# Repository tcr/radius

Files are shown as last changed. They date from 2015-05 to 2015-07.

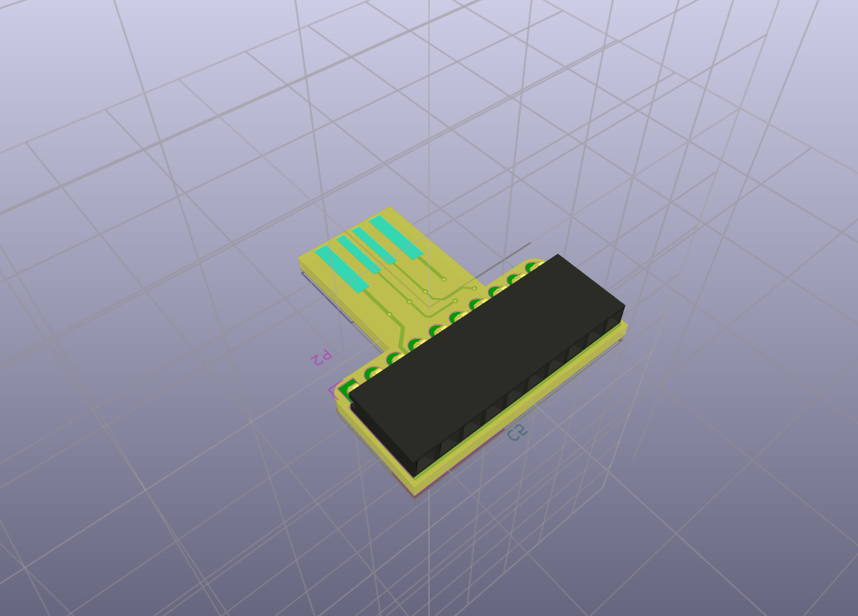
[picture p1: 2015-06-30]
board/renders/radiusm.png

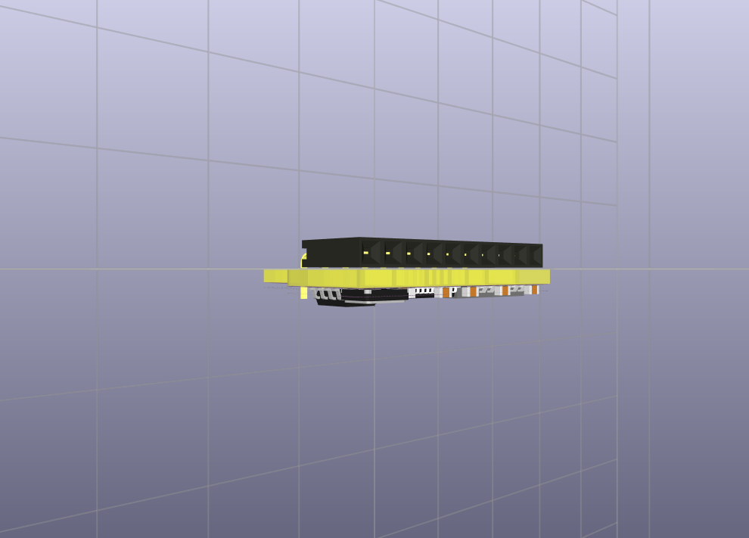
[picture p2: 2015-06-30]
board/renders/radius.png

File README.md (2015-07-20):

# radius



## testing

```
make
make flash
make test
```

If OS X reports contention for your device:

```
sudo kextunload -b com.apple.driver.AppleUSBCardReader
sudo kextunload -b com.apple.iokit.IOUSBMassStorageClass
```

## parts

Designator(s) | Quantity | Description | Part Number
--- | --- | --- | ---
IC1 | 1 | STM8S 8-bit micro (TSSOP-20) | [STM8S003F3P6](http://www.digikey.com/product-detail/en/STM8S003F3P6/497-11946-5-ND/2765682)
P2 | 1 | 10-pin right-angled header, .1" Pitch | [PPTC101LGBN-RC](http://www.digikey.com/product-search/en?KeyWords=S5446-ND&WT.z_header=search_go)
U1 | 1 | Full speed USB <-> 9-pin Serial (SOP-16) | CH340G
U2 | 1 | 3.3V Regulator (SO-8) | [LD1117D33CTR](http://www.digikey.com/scripts/DkSearch/dksus.dll?Detail&itemSeq=175125035&uq=635712533888642171)
Y1 | 1 | 12Mhz Crystal | [NX3225SA](http://www.digikey.com/product-detail/en/NX3225SA-12.000MHZ-STD-CSR-1/644-1047-1-ND/1128919)
C1 | 1 | 0.1 uF (0603) | ...
C2 | 1 | 10 uF (0603) | ...
C3 | 1 | 1 μF polarized (0603) | ...
C4, C5 | 2 | 20 pF (0603) | ...

* [STM8 Reference design](http://www.st.com/web/en/resource/technical/document/application_note/CD00194637.pdf#page=19)

## pin mapping

* GND
* 3.3V
* SCL - PB4
* SDA - PB5
* SCK - PC5
* MISO - PC7
* MOSI - PC6
* TXD - PD2
* RXD - PD0
* G3 - PD1

USB:

* TXD - PD6
* RXD - PD5

## docs

Reference manual: http://www.st.com/web/en/resource/technical/document/reference_manual/CD00190271.pdf

 * SPI: http://www.st.com/web/en/resource/technical/document/reference_manual/CD00190271.pdf#page=259
 * I2C: http://www.st.com/web/en/resource/technical/document/reference_manual/CD00190271.pdf#page=285
 * GPIO: http://www.st.com/web/en/resource/technical/document/reference_manual/CD00190271.pdf#page=106
 * UART: http://www.st.com/web/en/resource/technical/document/reference_manual/CD00190271.pdf#page=318

CPU reference: http://www.st.com/web/en/resource/technical/document/programming_manual/CD00161709.pdf

Product Datasheet: http://www.st.com/web/en/resource/technical/document/datasheet/DM00024550.pdf

 * Memory map: http://www.st.com/web/en/resource/technical/document/datasheet/DM00024550.pdf#page=32
 * Pin map: http://www.st.com/web/en/resource/technical/document/datasheet/DM00024550.pdf#page=22

 Errata: http://postar.sino-star.com/public/uploads/20120214161049_871.pdf

## CH340G

Datasheet: http://www.seeedstudio.com/wiki/images/7/7c/CH340DS1_EN.PDF

## tools

https://github.com/vdudouyt/stm8flash

```
brew install sdcc
```

http://www.colecovision.eu/stm8/128-EVAL%20Dhrystone.shtml

## how it works

interrupts are priority-based outputs in 64 byte packets. priority output is real time input of "uniterruptable streams", specifically i2c read (max 920Khz) and uart input (max 18400bps) simultaneously

also note that i2c can stretch clock lines so really it's only uart interrupts

there are many buffers, but this one is mine(d) for its outputting content. all packets block on new input until it's swapped for the outputting. so buffers must clean faster than they collectively are filled for uninterruptable streams (and acks).

output from radius is asap and dumped into its buffers. simple packet id +  NACK/ACK acknowledgement byte on the usb line.

ID0 + NACK/ACK
ID1 + LEN + <=64 byte packet

input? it is 64 byte packets. wait for an nack, then resend, or continue

LEN + <=64 byte packet

input is synced at start by waiting for an 'R' on both sides

packets are USB-style repeated until a 0 length packet or < 64 length packet is received

## license

MIT/ASL2

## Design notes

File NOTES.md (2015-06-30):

--------  --------
WRIPKT
  -------- --------
  RECV RX

RX faster than TX

async events have no ack, simply are expected to be sent out when buffered and have their buffer cleared before more data comes in

thus tx needs to be faster than rx for async
if there are two async streams, faster than both buffers filling simultaneously
double-buffered so it's always cleared first

swapped buffers for data reception for each channel
so, 4 out + 4 in + 2 active buffers

I2C TRANSFER OUT

TX double buffer
RX double buffer

enum ack_t {
	NACK = 0x00,
	ACK,
}

enum out_t {
	OUT_CONTROL = 0x10,
	OUT_I2C,
	OUT_UART,
	OUT_SPI,
};

enum in_t {
	IN_UART = 0x20,
	IN_SPI,
	IN_I2C,
	IN_GPIO (interupt or read)
};

SETUP [CONTROL TRANSFER]
- begin i2c transfer; tx and rx
- begin spi transfer; tx and rx
- begin uart transfer; tx
- set gpio output and/or read
- 

data packets
-> [byte] [16 bytes]
<- [ack] or [nack]
<- or impulse

OUT -> I2C MASTER TX
OUT -> UART TX
OUT -> SPI MASTER TX

IN -> UART RX (hi-pri)
IN -> I2C MASTER RX
IN -> SPI MASTER RX
IN -> GPIO INTERRUPT OR READ

1. uart fills buffers
2. main loop handles control elements buffers
3. other loops handle other buffers
4. acks only when empty

(so data packet of i2c data preceding i2c transfer is ok)

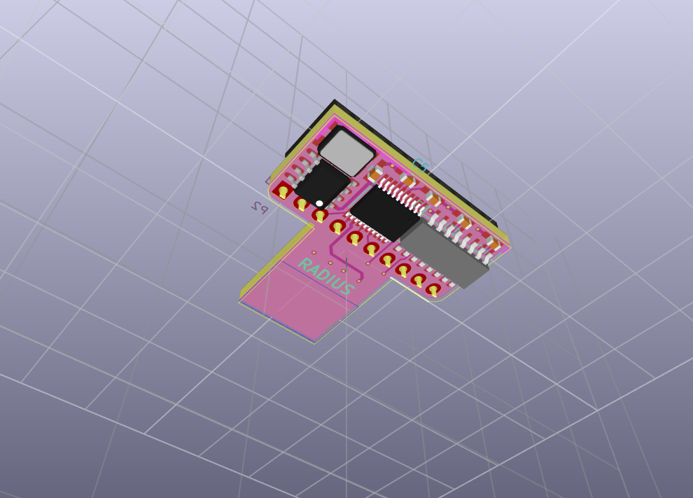
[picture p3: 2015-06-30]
board/renders/radiusn.png

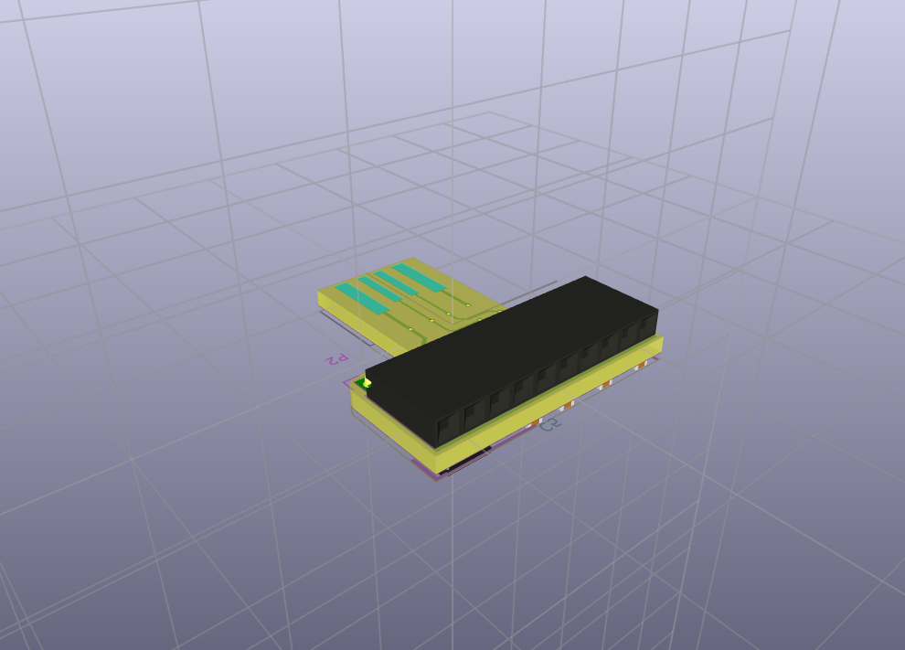
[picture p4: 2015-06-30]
board/renders/radiusj.png

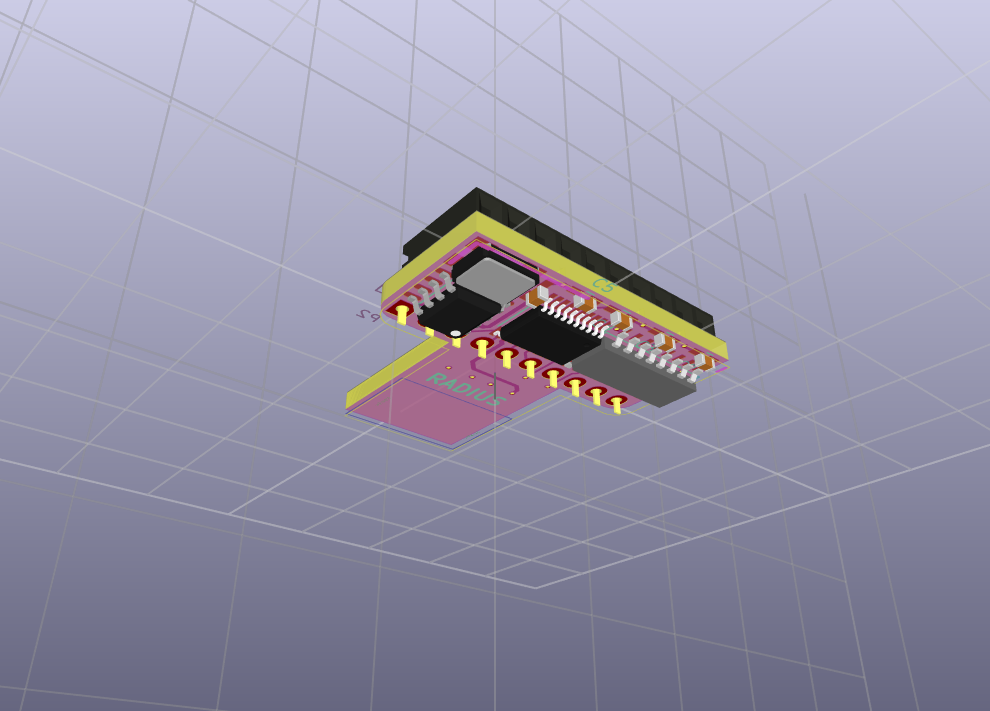
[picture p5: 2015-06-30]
board/renders/radiusk.png

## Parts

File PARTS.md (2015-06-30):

10 - 0.5 = 9.5

8

BOM=2.5

cpu=~1
#stm32f0=~0.5

attiny24=~0.42
https://octopart-clicks.com/click/track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
https://www.obdev.at/products/vusb/index.html

CH340G
http://www.aliexpress.com/wholesale?SearchText=CH340G&opensearch=true
~0.21-0.37

stm8s=~0.22-0.33
https://octopart-clicks.com/click/track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
http://www.aliexpress.com/w/wholesale-stm8s.html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
http://www.st.com/web/en/resource/technical/document/application_note/CD00194637.pdf

power
http://www.digikey.com/product-search/en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
0.15-0.23

header
http://www.digikey.com/product-detail/en/PPTC101LGBN-RC/S5446-ND/775904
0.58-.94

crystal

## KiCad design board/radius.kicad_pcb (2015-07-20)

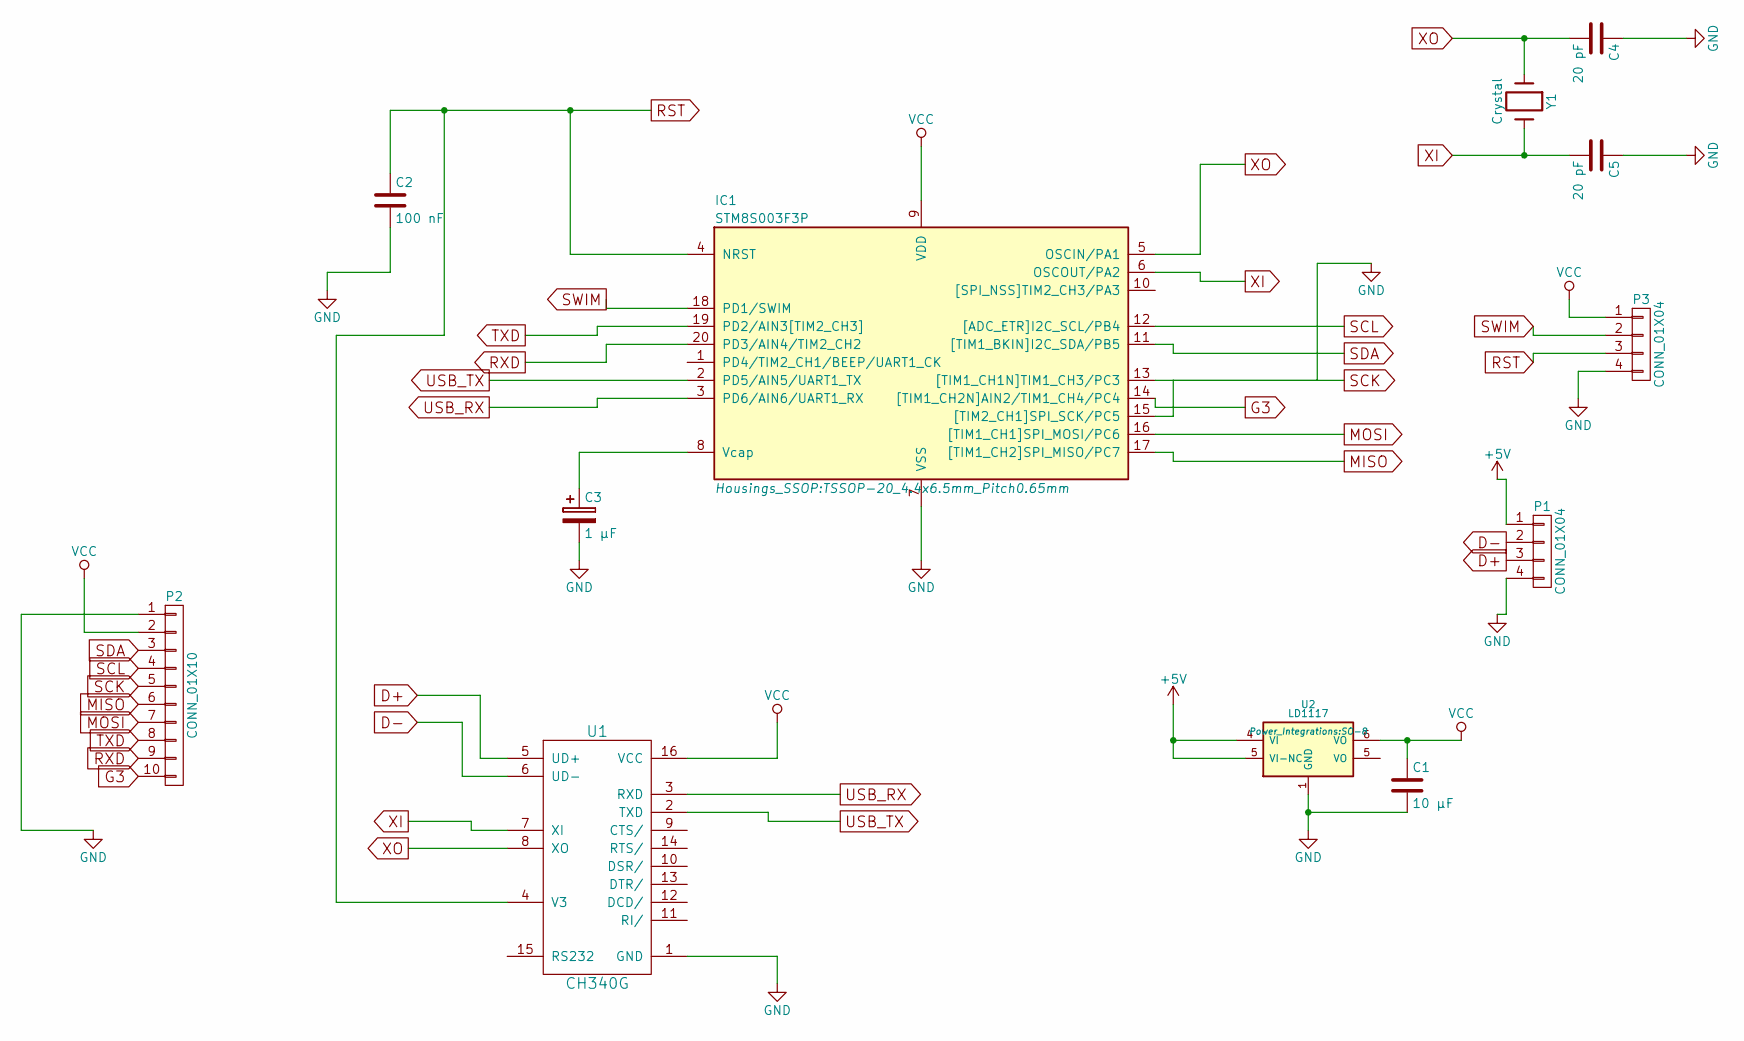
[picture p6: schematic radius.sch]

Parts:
C1: 10 µF; C_0603_HandSoldering
C2: 100 nF; C_0603_HandSoldering
C3: 1 μF; C_0603_HandSoldering
C4, C5: 20 pF; C_0603_HandSoldering
IC1: STM8S003F3P; TSSOP-20_4.4x6.5mm_Pitch0.65mm
P1: CONN_01X04; USB-A-PCB
P2: CONN_01X10; Socket_Strip_Angled_1x10
P3: CONN_01X04; RADIUS-CONN-2MM-M-1x4
U1: CH340G; SO-16-N
U2: LD1117; SO-8
Y1: Crystal; Crystal_SMD_0603_4Pads

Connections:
+5V: P1.1, U2.4 (VI), U2.5 (VI-NC)
D+: P1.3, U1.5 (UD+)
D-: P1.2, U1.6 (UD-)
G3: IC1.14 ([TIM1_CH2N]AIN2/TIM1_CH4/PC4), P2.10
GND: C1.2, C2.2, C3.2, C4.1, C5.1, IC1.7 (VSS), IC1.13 ([TIM1_CH1N]TIM1_CH3/PC3), P1.4, P2.1, P3.4, U1.1 (GND), U2.1 (GND)
MISO: IC1.17 ([TIM1_CH2]SPI_MISO/PC7), P2.6
MOSI: IC1.16 ([TIM1_CH1]SPI_MOSI/PC6), P2.7
unnamed: C3.1, IC1.8 (Vcap)
RST: C2.1, IC1.4 (NRST), P3.3, U1.4 (V3)
RXD: IC1.20 (PD3/AIN4/TIM2_CH2), P2.9
SCK: IC1.15 ([TIM2_CH1]SPI_SCK/PC5), P2.5
SCL: IC1.12 ([ADC_ETR]I2C_SCL/PB4), P2.4
SDA: IC1.11 ([TIM1_BKIN]I2C_SDA/PB5), P2.3
SWIM: IC1.18 (PD1/SWIM), P3.2
TXD: IC1.19 (PD2/AIN3[TIM2_CH3]), P2.8
USB_RX: IC1.3 (PD6/AIN6/UART1_RX), U1.3 (RXD)
USB_TX: IC1.2 (PD5/AIN5/UART1_TX), U1.2 (TXD)
VCC: C1.1, IC1.9 (VDD), P2.2, P3.1, U1.16 (VCC), U2.6 (VO)
XI: C5.2, IC1.6 (OSCOUT/PA2), U1.7 (XI), Y1.2
XO: C4.2, IC1.5 (OSCIN/PA1), U1.8 (XO), Y1.1

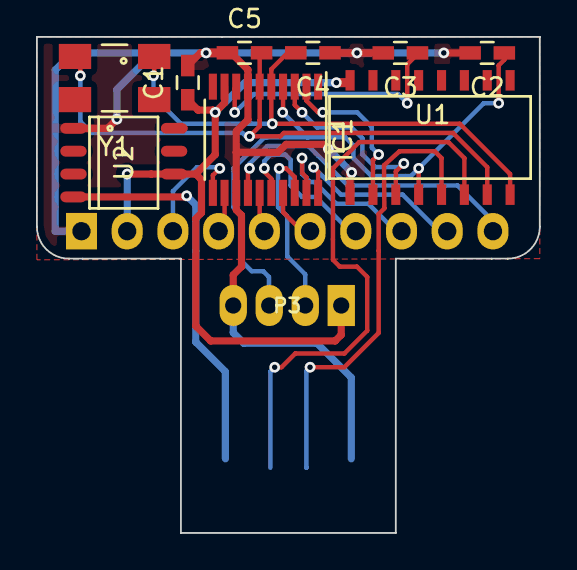
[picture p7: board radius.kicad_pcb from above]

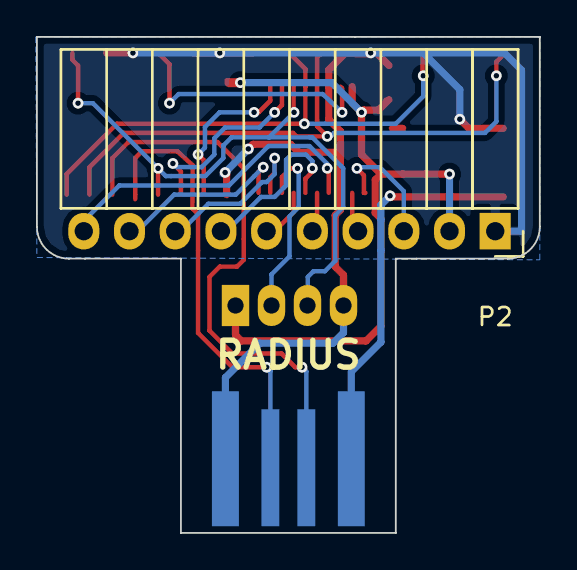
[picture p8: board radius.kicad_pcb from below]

Board: 2 copper layers, 27.9 x 27.6 mm, 12 parts (2 on the bottom side), 20 nets.

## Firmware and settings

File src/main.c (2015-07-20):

#include <stdio.h>
#include <string.h>
#include <stdint.h>

#include "stm8s.h"
#include "lib.h"
#include "coroutine.h"

char uartstr[16] = "\0\0\0\0\0\0\0\0\0\0\0\0\0\0\0";
const uint8_t uartstr_len = 12;
volatile uint8_t pos = 0;

volatile uint8_t I2C_ReadByte_Result_Addr = 0;
volatile uint8_t I2C_ReadByte_Result_Reg = 0;
volatile uint8_t I2C_ReadByte_Result_Ready = 1;
volatile uint8_t I2C_ReadByte_Result_Value[32] = { 0 };
volatile size_t I2C_ReadByte_Count = 0;
volatile size_t I2C_ReadByte_Pos = 0;

void irq_i2c (void) __interrupt(IRQ_I2C) {
    static uint8_t Temp, Byte_Read;

    scr_begin;

    gpio_write(0, 1);
    while (I2C_ReadByte_Result_Ready) {
        scr_return_void;
    }

    // while((I2C_SR3 & 0x02) != 0);

    while ((I2C_SR1 & 0x01) == 0) { //Start condition generated
        scr_return_void;
    }

    I2C_DR = (I2C_ReadByte_Result_Addr << 1);         //Device address
    // if ((I2C_SR1 & 0x80) == 0); //Data register empty (transmitters)
    while ((I2C_SR1 & 0x02) == 0) { //Address sent
        scr_return_void;
    }
    Temp = I2C_SR3;        //Status register

    I2C_DR = I2C_ReadByte_Result_Reg;         //Device register
    while ((I2C_SR1 & 0x80) == 0) { //Data register empty (transmitters)
        scr_return_void;
    }

    // Writing
    // I2C_DR = Data;         //Device data
    // while((I2C_SR1 & 0x80) == 0); //Data register empty (transmitters)
    // I2C_CR2 |= 0x02;        //I2C Stop Condition
    // This might be wrong; other code used a wait?
    // while ((I2C_SR1 & 0x40) == 0) { //Byte transfer finished
    //   scr_return_void;
    // }
    // i = 0xFFFF;
    // while(i--);
    // scr_finish_void;

    I2C_CR2 |= 0x01;        //I2C Start Condition
    while ((I2C_SR1 & 0x01) == 0) { //Start condition generated
        scr_return_void;
    }

    I2C_DR = ((I2C_ReadByte_Result_Addr << 1) | 0x01);    //Device address(read)
    scr_return_void;
    while ((I2C_SR1 & 0x02) == 0) { //Address sent
        scr_return_void;
    }
    Temp = I2C_SR3;        //Status register

    do {
        if (I2C_ReadByte_Count > 1) {
            I2C_CR2 |= 0x04;        //I2C Ack Condition
        } else {
            I2C_CR2 |= 0x02;        //I2C Stop Condition
        }
        scr_return_void;

        while ((I2C_SR1 & 0x40) == 0) { //Byte transfer finished
          scr_return_void;
        }
        // Byte_Read = 0x00;        //Clean data
        I2C_ReadByte_Result_Value[I2C_ReadByte_Pos++] = I2C_DR;
    } while ((--I2C_ReadByte_Count) > 0);

    I2C_ReadByte_Result_Ready = 1;

    scr_finish_void;
}

void i2c_read_bytes (uint8_t addr, uint8_t reg, size_t count) {
    I2C_ReadByte_Result_Addr = addr;
    I2C_ReadByte_Result_Reg = reg;
    I2C_ReadByte_Count = count;
    I2C_ReadByte_Pos = 0;
    I2C_ReadByte_Result_Ready = 0;
    gpio_write(0, 0);
    I2C_CR2 |= 0x01;        //I2C Start Condition
}

uint8_t i2c_read_byte_result () {
    return I2C_ReadByte_Result_Ready ? 0 : 1;
}

void write_chars (char* to, uint8_t val) {
    uint8_t high = val >> 4;
    uint8_t low = val & 0xf;
    to[0] = high > 0x9 ? 0x61 + (high - 0xa) : 0x30 + high;
    to[1] = low > 0x9 ? 0x61 + (low - 0xa) : 0x30 + low;
}

void uart_tx (void) __interrupt(IRQ_UART1) {
    if (uart_tx_complete()) {
        if (pos < uartstr_len) {
            uart_write(uartstr[pos]);
            ++pos;
        } else {
            // UART1_CR2->TCIEN = 1;
            // UART1_CR2->TIEN = 0; 
            UART1_CR2->TCIEN = 0;
        }
    }
    // if (UART1_CR2->TCIEN && uart_tc_complete()) {
    //     UART1_CR2->TCIEN = 0;
    //     UART1_CR2->TEN = 0;
    // }
}

volatile int doread = 0;
volatile uint8_t rx_read = 0;

void uart_rx (void) __interrupt(IRQ_UART1_FULL) {
    scr_begin;

    while (1) {
        rx_read = USART1_DR;
        if (rx_read == 'R') {
            break;
        }
        scr_return_void;
    }

    rx_read = USART1_DR;
    doread = 1;

    // gpio_write(0, 1);

    //     uart_write(uartstr[0]);
    //     uart_write(uartstr[1]);
    //     uart_write(uartstr[2]);
    //     uart_write(uartstr[3]);
    
    scr_finish_void;
}


void irq_timer2 (void) __interrupt(IRQ_TIM2) {
    //  Reset the interrupt otherwise it will fire again straight away.
    TIM2_SR1->UIF = 0;
}

//
//  Main program loop.
//
void main (void) {
    volatile uint8_t a;
    uint8_t regread;
    int32_t c;
    int32_t f;
    size_t i;

    __disable_interrupt();
    init_clock();
    init_timer2();
    init_i2c();
    config_ports();
    config_timer2();
    config_uart();
    gpio_write(0, 0);
    __enable_interrupt();

    // 
    // uart_write('A');
    while (1) {

        // uart_write(celsval);
        __wait_for_interrupt();

        if (doread) {
            // looper();
            doread = 0;
            // uart_write(uartstr[0]);
            // uart_write('!');
            // gpio_write(0, gpio_read(0));

            i2c_read_bytes(0x1D, rx_read, 1);
            while (i2c_read_byte_result()) {
                __wait_for_interrupt();
            }

            for (i=0;i<6;i++) {
                uartstr[i] = I2C_ReadByte_Result_Value[i];    
            }

            // if (regread == 0x2A) {
                pos = 0;
                UART1_CR2->TCIEN = 1;
            // }
        }

        //     doread = 0;
        //     pos = 0;



            // c = ((17572 * tempraw) >> 16) - 4685;
            // f = (1.8 * c) + 3200;

            // write_chars(&uartstr[0], ((uint8_t*) &c)[3]);
            // write_chars(&uartstr[2], ((uint8_t*) &c)[2]);
            // write_chars(&uartstr[4], ((uint8_t*) &c)[1]);
            // write_chars(&uartstr[6], ((uint8_t*) &c)[0]);
        // }

        // if (uart_rx_available()) {
        //     volatile uint8_t a = USART1_DR;
            // gpio_write(0, 1);
        // }
    }
}

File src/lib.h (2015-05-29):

#ifndef __LIB_H__
#define __LIB_H__

#include <stdio.h>
#include <string.h>
#include <stdint.h>

#include "stm8s.h"

inline void gpio_input (volatile port_t * port, uint8_t pin) {
	uint8_t value = port->DDR;
	port->DDR = value & ~(1 << pin);
}

inline void gpio_output (volatile port_t * port, uint8_t pin) {
	uint8_t value = port->DDR;
	port->DDR = value | (1 << pin);
}

inline uint8_t gpio_read (uint8_t pin) {
	uint8_t value = PORT_D->ODR;
	return (value >> pin) & 0x1;
}

inline void gpio_write (uint8_t pin, uint8_t val) {
	uint8_t value = PORT_D->ODR;
	PORT_D->ODR = (value & ~(1 << pin)) | (1 << val);
}

//
//  Reset Timer 2 to a known state.
//
inline void init_timer2()
{
    TIM2_CR1_REG = 0;               // Turn everything TIM2 related off.
    TIM2_IER_REG = 0;
    TIM2_SR2 = 0;
    TIM2_CCER1 = 0;
    TIM2_CCER2 = 0;
    TIM2_CCER1 = 0;
    TIM2_CCER2 = 0;
    TIM2_CCMR1 = 0;
    TIM2_CCMR2 = 0;
    TIM2_CCMR3 = 0;
    TIM2_CNTRH = 0;
    TIM2_CNTRL = 0;
    TIM2_PSCR = 0;
    TIM2_ARRH  = 0;
    TIM2_ARRL  = 0;
    TIM2_CCR1H = 0;
    TIM2_CCR1L = 0;
    TIM2_CCR2H = 0;
    TIM2_CCR2L = 0;
    TIM2_CCR3H = 0;
    TIM2_CCR3L = 0;
    TIM2_SR1_REG = 0;
}


//
//  Setup Timer 2 to generate a 20 Hz interrupt based upon a 16 MHz timer.
//
inline void config_timer2()
{
    TIM2_PSCR = 0x06;       //  Prescaler = 8.
    TIM2_ARRH = 0xff;       //  High byte of 50,000.
    TIM2_ARRL = 0xff;       //  Low byte of 50,000.
    TIM2_IER->UIE = 1;       //  Enable the update interrupts.
    TIM2_CR1->CEN = 1;       //  Finally enable the timer.
}

inline uint16_t read_timer1 (void) {
	uint8_t h = TIM1_CNTRH;
	uint8_t l = TIM1_CNTRL;
	return((uint16_t)(h) << 8 | l);
}


inline void config_ports (void) {
	gpio_output(PORT_D, 0);
	gpio_output(PORT_D, 5);
    // gpio_output(PORT_B, 5);
    // gpio_output(PORT_B, 4);

	gpio_input(PORT_D, 6);

PORT_B->DDR &= 0xcf;
PORT_B->CR1 &= 0xcf;
PORT_B->CR2 &= 0xcf;
}

inline void uart1_2400 (void) {
    USART1_BRR1 = 0xA0;
    USART1_BRR2 = 0x1B;
}

inline void uart1_9600 (void) {
    USART1_BRR1 = 0x68;
    USART1_BRR2 = 0x03;
}

inline void uart1_19200 (void) {
    USART1_BRR1 = 0x34;
    USART1_BRR2 = 0x01;
}

inline void uart1_57600 (void) {
    USART1_BRR1 = 0x11;
    USART1_BRR2 = 0x06;
}

inline void uart1_115200 (void) {
    USART1_BRR1 = 0x08;
    USART1_BRR2 = 0x0B;
}

inline void uart1_230400 (void) {
    USART1_BRR1 = 0x04;
    USART1_BRR2 = 0x05;
}

inline void uart1_460800 (void) {
    USART1_BRR1 = 0x02;
    USART1_BRR2 = 0x03;
}

inline void uart1_921600 (void) {
    USART1_BRR1 = 0x01;
    USART1_BRR2 = 0x01;
}

inline void config_uart (void) {
    assign_reg(UART1_CR2, { .TCIEN = 0, .TEN = 1, .RIEN = 1, .REN = 1 });
    assign_reg(UART1_CR3, { .STOP = UART1_CR2_STOP_TWO });
    uart1_57600();
}

inline uint8_t uart_tx_complete (void) {
	return USART1_SR & USART_SR_TXE;
}

uint8_t uart_rx_available (void) {
	return USART1_SR & USART_SR_RXNE;
}

inline uint8_t uart_tc_complete (void) {
    return USART1_SR & USART_SR_TC;
}

inline void uart_wait () {
	// gpio_write(0, 1);
	while(!(USART1_SR & USART_SR_TXE));
	// gpio_write(0, 0);
}

inline void uart_write (char c) {
	USART1_DR = c;
}

inline void init_clock (void) {
    CLK_CKDIVR = 0x00; // Set the frequency to 16 MHz
    // CLK_PCKENR2 |= 0x02; // Enable clock to timer
    CLK_PCKENR1 = 0xFF; // Enable peripherals
}

inline void init_i2c (void) {
    I2C_CR1 = 0x00; //Disable I2C
    I2C_CR2 = 0x04; //Acknowledge enable

    // Program the peripheral input clock in I2C_FREQR Register in order to generate correct timings.
    I2C_FREQR = 10; //Peripheral clock frequency = 1~24mHz

    // Configure the rise time register
    // I2C_OARH = 0x40; //Addressing mode = 10-bit slave address (7-bit address not acknowledged)
    I2C_OARH = 0x00; //Addressing mode = 7-bit slave address (10-bit address not acknowledged)
    I2C_OARL = 0x00; //Interface address
    I2C_ITR = 0x06; //Interrupt register

    // Configure the clock control registers
    I2C_CCRH = 0x80; //I2C master mode selection = Fast mode I2C
    I2C_CCRL = 30;  //Clock control register (Master mode)

    // Program the I2C_CR1 register to enable the peripheral
    I2C_CR1 = 0x01; //Enable I2C
}

#endif

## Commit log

2015-05-05 Supports timers.
2015-05-05 Adds UART output.
2015-05-06 Supports echo over UART.
2015-05-22 Adds pin mapping.
2015-05-23 Successfully reads accelerometer ID.
2015-05-23 Interrupt-based I2C transmission.
2015-05-23 Corrects UART interrupts to handle Rx.
    [lib.h, main.c]
2015-05-23 Corrects test to work with I2C.
    [main.c, test.js]
2015-05-26 Switches to using a value buffer.
2015-05-26 Fixes multibyte I2C transfer.
    [main.c]
2015-05-26 Supports multibyte I2C read.
2015-05-29 Adds make target to unload drivers.
2015-06-16 Adds initial schematic files.
    [radius.sch]
2015-06-18 Commit #2
    [radius.kicad_pcb, radius.sch]
2015-06-18 New change
    [radius.kicad_pcb]
2015-06-18 Cleans up upper components.
    [radius.kicad_pcb]
2015-06-18 Qualifying layout
    [radius.kicad_pcb, radius.sch]
2015-06-24 Tighest layout
    [radius.kicad_pcb]
2015-06-25 Adds missing capacitor on regulator.
    [radius.sch]
2015-06-26 Adds USB connector.
    [radius.kicad_pcb, radius.sch]
2015-06-26 Expands footprint of board.
    [radius.kicad_pcb]
2015-06-28 Corrects footprints for CH340G, start over.
    [radius-old.kicad_pcb, radius.kicad_pcb, radius.sch]
2015-06-29 Thicker traces.
    [radius.kicad_pcb]
2015-06-29 New alignment.
    [radius-footprints.kicad_pcb, radius.kicad_pcb]
2015-06-29 Board edges.
    [radius.kicad_pcb]
2015-06-29 Completed edges.
    [radius.kicad_pcb]
2015-06-29 Completes power rails, layout.
    [radius.kicad_pcb, radius.sch]
2015-06-30 Updates paths for files. adds renders, gerbers.
    [radius-B_Cu.gbr, radius-B_Mask.gbr, radius-B_SilkS.gbr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]
2015-06-30 Removes old footprints.
    [radius-footprints.kicad_pcb, radius-old.kicad_pcb]
2015-06-30 Updates Capacitor values.
    [radius.kicad_pcb, radius.sch]
2015-07-20 Widens board to 1.1"
    [radius.kicad_pcb]
2015-07-20 Support SWIM connector.
    [radius.kicad_pcb, radius.sch]
2015-07-20 Corrects power adapter pinout.
    [radius.kicad_pcb, radius.sch]
2015-07-20 Flips RADIUS text side.
    [radius.kicad_pcb]
